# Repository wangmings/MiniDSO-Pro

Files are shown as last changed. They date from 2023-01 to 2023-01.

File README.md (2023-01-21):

# MiniDSO-Pro

#### 介绍
B站老刘示波器Pro版本，在原版的基础上，扩展了测量负电压的功能，更新了UI设计，屏幕升级为1.3寸OLED屏。你可以在doc文件夹，获取设计报告和相关的芯片数据手册。

请大家务必给我个Star！！！这真的很重要！

B站视频演示：[点击我观看](https://www.bilibili.com/video/BV1M5411u7B6)

3D仿真效果图:
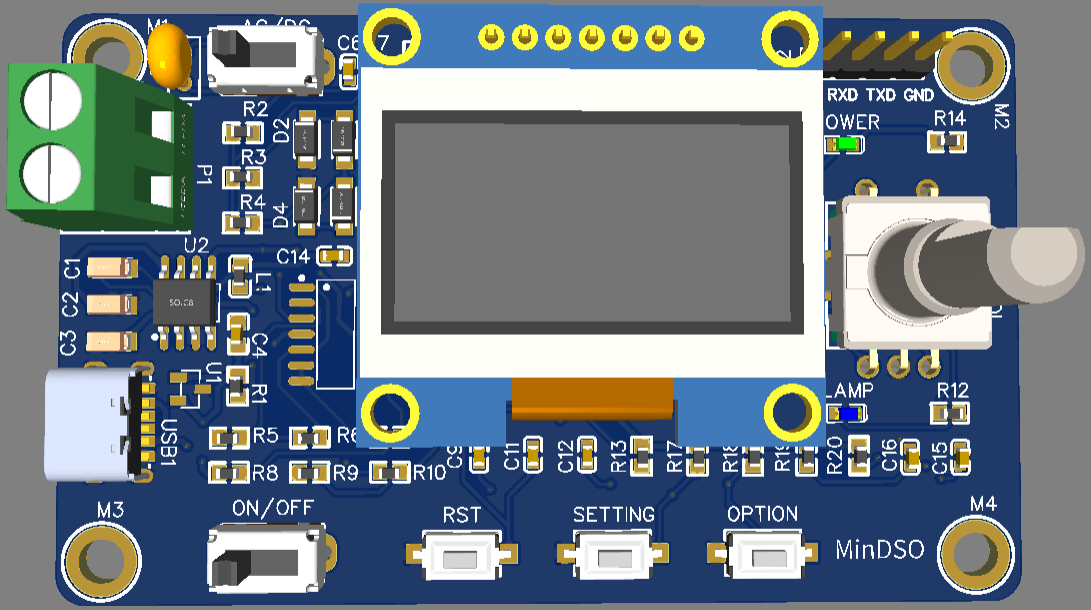
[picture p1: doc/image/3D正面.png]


2D仿真效果图:
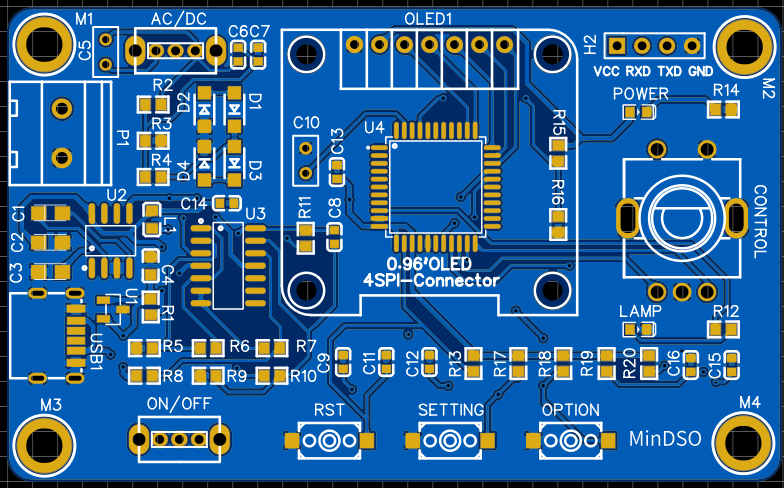
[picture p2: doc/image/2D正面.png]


实物效果图:
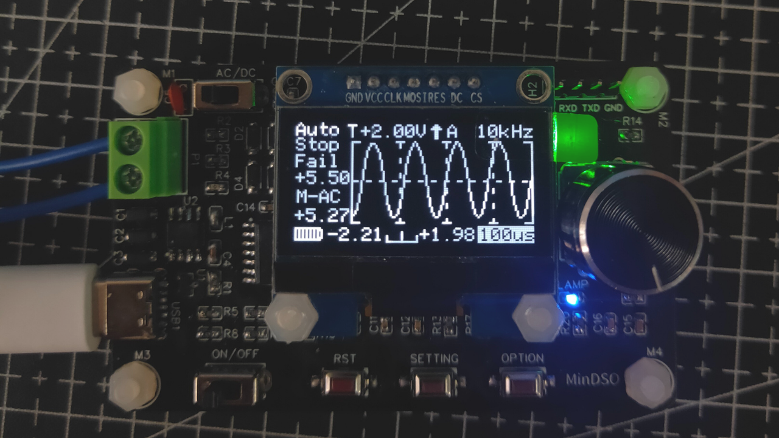
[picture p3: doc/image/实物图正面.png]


#### 系统架构

Mini示波器采用了一套成本低廉但高效的硬件，配合层次化的软件框架，实现对常规低频信号波形的采集、分析、显示。

硬件部分的主要工作有：电源管理（5V、2.5V、-5V）；对信号的衰减、限幅、偏置。最后将处理好的电压信号送入MCU的ADC外设，进行数据采集。由于ADC外设只能采集正电压，因此我们通过增加偏置电压的方式，将负电压抬高来采集。

软件部分的主要工作有：底层驱动SDK框架、ADC滤波算法、波形数据处理、人机交互界面。SDK提供基本的模块和外设驱动支持，滤波算法去除噪声和毛刺，波形处理计算电压值和频率，并为波形显示做准备；人机交互界面提供屏幕显示（OLED屏）和操作方式（旋钮和按键）。

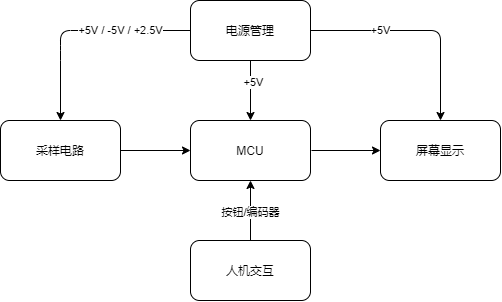
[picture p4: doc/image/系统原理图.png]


#### 与原版对比

这一版本的Mini示波器-Pro，相比于原版对硬件部分做了很大扩展，使其可以测到负电压。软件部分修改了有30%，主要是在数据处理和UI显示部分。

#### 调参教程

示波器采样的原理与原版一致，但是由于硬件上加了许多电路，导致信号呈非线性变化，因此需要对系统计算的结果进行处理。

这里提供两种办法：

##### 1. 对原采样方法进行改进
原版的采样模式，是利用了芯片自带的12位ADC进行采样，所以可以对ADC的采样函数进行优化。原版使用了查询法，通过循环等待采样完成标志位，获取采样结果。

频率的计算，是根据不同的采样时间（delay延时等待法），来分段计算频率值。这里可以通过定时器来控制采样时间，提高精确度。

##### 2. 对原采样结果上进行拟合

直接在原版的采样结果上进行数据拟合，这样做比较快捷，也是我用的方法（主要是赶时间）。但是误差较大，且需要测算的数据量有一点多。

具体的方法是，首先记录原采样的结果，电压幅度的刻度为0.5V，范围是从0V到20V。 频率的刻度为1KHz，范围是从0KHZ到20KHz。将测算的结果与输入的信号，一一对应拟合出计算公式，我采用的Excel来操作，选择的是对数函数来拟合，数据有误差。

具体需要拟合的函数在chart.c文件中，函数名称如下：

```C
/* 需要拟合数据的函数如下：*/
void getWaveFreq(void);
void AnalyseData(void);

/* 拟合数据的结果存放在如下变量：*/
VMax_m  /* 存放电压最大值 */
VMin_m  /* 存放电压最小值 */
Mvoltage  /* 存放电压平均值 */

WaveFreq   /* 存放频率值 */

```
开发者在调参的时候，可以屏蔽我的拟合代码，进行原方法采样结果的记录，然后进行数据拟合。我会在代码中进行标注，方便开发者查找和修改。

#### 需要改进的地方

1.硬件的性能还没有全部发挥出来，测量幅度还可以更高。
2.MCU的性能还没有榨干，比如没有用上硬件SPI，提高屏幕刷新率。

#### 开发后记

1.最一开始设想的方案，我是想用上我写的AntOS操作系统的，但是初版操作系统，为合作式调度，实际使用的过程中，并没有达到我的预期效果，所以选择在老刘示波器的基础工程上修改和优化。

2.硬件设计主要参考了B站`唐老师讲电赛`大佬提供的方案，实际使用的过程中，我又微调了一部分，建议大家可以去阅读一下硬件电路中使用的几种芯片数据手册，这样心里更有底，不然遇到问题不好排查。

3.大多数元器件，我用的都是0603的封装，这样可以让PCB板设计的更小巧更紧凑，但是不好焊接。

4.下一版本，我将使用STC8AxD4作为主控（因为有DMA）,软件上使用我现在编写AntOS（已支持抢占式调度），进一步提高示波器的性能。

####原版示波器Github仓库连接

[点击我跳转]( https://github.com/CreativeLau/Mini-DSO)

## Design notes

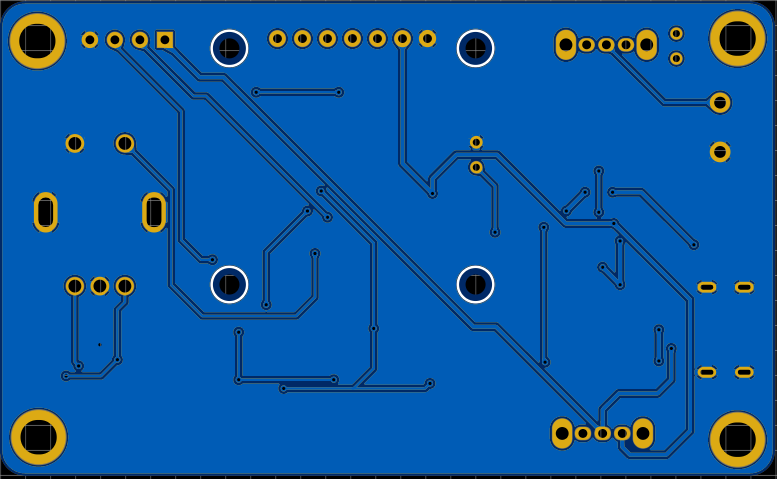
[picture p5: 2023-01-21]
doc/image/2D反面.png

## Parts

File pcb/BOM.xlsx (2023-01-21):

ID | Name | Designator | Footprint | Quantity | Manufacturer Part | Manufacturer | Supplier | Supplier Part | Price | JLCPCB Part Class
1 | SS-12D02-VG4 | AC/DC,ON/OFF | SW-TH_SS-12D02-VG4 | 2 | SS-12D02-VG4 | Rectangular Connectors - Contacts | LCSC | C136719 | 0.4547
2 | 10uF | C1,C2,C3 | CASE-A_3216 | 3
3 | 4.7uf | C4 | C0603 | 1 |  |  | LCSC
4 | 100nF(104) | C5 | 插件陶瓷电容 | 1 | CY1331KE1IEB45G0A2 | Dersonic | LCSC | C263248 | 0.1958 | Extended Part
5 | 30pF | C6,C7 | C0603 | 2
6 | 1uF | C8,C9,C11,C12 | C0603 | 4
7 | 1000pF | C10 | 插件陶瓷电容 | 1 | 102M 400V Y5V | ReliaPro | LCSC | C3704 | 0.1942
8 | 0.1uF | C13,C14,C15,C16 | C0603 | 4
9 | EC11E152U402 | CONTROL | SW-TH_EC11XXXXXXXX | 1 | EC11E152U402 | ALPS Electric | LCSC | C110313 | 32.76
10 | 1N4148W | D1,D2,D3,D4 | SOD-123FL_L2.6-W1.6-LS3.4-RD | 4 | 1N4148W | Tak Cheong | LCSC | C129216 | 0.0901
11 | HDR-F-2.54_1x4 | H2 | HDR-M-2.54_1X4 | 1 |  |  | LCSC | C225501 | 0.4719
12 | 0.1uH | L1 | L0603 | 1
13 | LED-0603_B | LAMP | LED0603_BLUE | 1 | 19-217/BHC-ZL1M2RY/3T | EVERLIGHT(台湾亿光) | LCSC | C72041 | 0.1007
14 | M3螺丝孔 COPY | M1,M2,M3,M4 | M3螺丝孔 | 4
15 | 0.96OLED_7P | OLED1 | 0.96OLED_7P | 1 |  |  | LCSC
16 | K2-3.6×6.1_SMD | OPTION,RST,SETTING | KEY-SMD_2P-L6.2-W3.6-LS8.0 | 3 | K2-1107ST-A4SW-06 |  | LCSC | C118141 | 0.341
17 | WJ128V-5.0-2P | P1 | CONN-TH_2P-P5.00_WJ128V-5.0-2P | 1 | WJ128V-5.0-2P | ReliaPro | LCSC | C8269 | 0.7299 | Extended Part
18 | LED-0603_G | POWER | LED0603_GREEN | 1 | 19-217/GHC-YR1S2/3T | EVERLIGHT(台湾亿光) | LCSC | C72043 | 0.1549
19 | 649Ω | R1 | R0603 | 1
20 | 2k | R3 | R0603 | 1
21 | 0Ω | R4 | R0603 | 1
22 | 1.8k | R5 | R0603 | 1
23 | 3.2k | R6 | R0603 | 1
24 | 4.7k | R7,R8,R9,R10 | R0603 | 4
25 | 10Ω | R11 | R0603 | 1
26 | 10K | R2,R15 | R0603 | 2
27 | 2K | R16 | R0603 | 1
28 | 3.3k | R12,R13,R14,R17,R18 | R0603 | 5
29 | 10k | R19,R20 | R0603 | 2
30 | TL431 | U1 | SOT-23-3_L2.9-W1.3-P1.90-LS2.4-BR | 1 | TL431 | ZRE(治润) | LCSC | C779770 | 0.1699
31 | ICL7660SCBAZ-T | U2 | SOIC-8_L4.9-W3.9-P1.27-LS6.0-BL | 1 | ICL7660SCBAZ-T | Renesas Electronics | LCSC | C357815 | 6.3 | Extended Part
32 | TL074CDT | U3 | SOIC-14_L8.7-W3.9-P1.27-LS6.0-BL | 1 | TL074CDT | STMicroelectronics | LCSC | C6963 | 1.5521 | Extended Part
33 | STC8A8K64S4A12-C83896 | U4 | LQFP-44_L10.0-W10.0-P0.80-LS12.0-BL | 1 | STC8A8K64S4A12 | STC Micro | LCSC | C83896 | 24.75 | Extended Part
34 | TYPEC-250D-BCP6 | USB1 | USB-C-SMD_TYPEC-250D-BCP6 | 1 | TYPEC-250D-BCP6 | XUNPU | LCSC | C720626 | 0.4803

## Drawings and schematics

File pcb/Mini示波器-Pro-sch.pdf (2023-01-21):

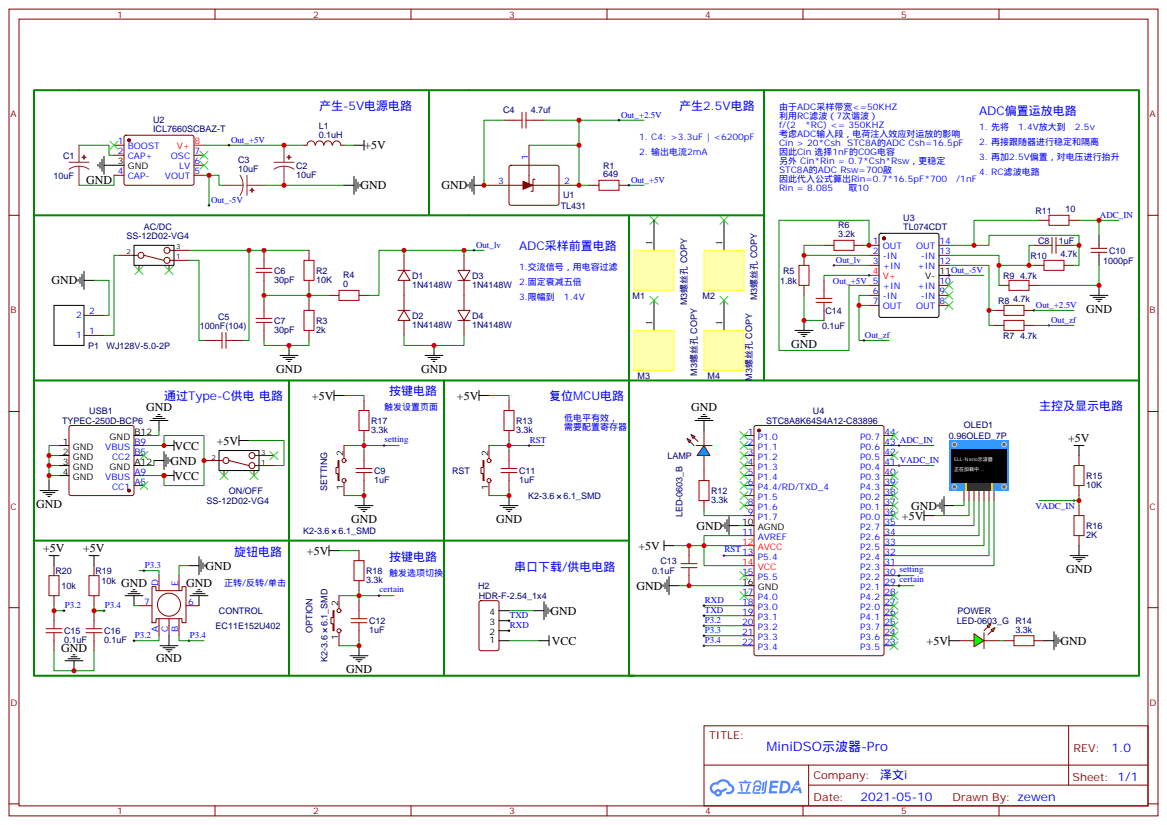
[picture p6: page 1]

+IN 10 V- 11 +IN 12 -IN 13 OUT 14

CC1 A5 VBUS A9 GND A12 CC2 B5 VBUS B9 GND B12

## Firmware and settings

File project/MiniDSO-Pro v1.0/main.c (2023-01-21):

/*

    简易示波器

    操作说明：
        主界面-选项设置模式（按Option按键）：
            单击编码器：切换开始/暂停采样
            按下同时旋转编码器：在参数间切换

        主界面-波形水平滚动模式：
            单击编码器：切换开始/暂停采样
            旋转编码器：水平滚动波形（在暂停采样状态下有效）
            按下同时旋转编码器：垂直滚动波形（仅在暂停采样状态下有效）
            
        设置界面（按Setting按键）：

            长按编码器：返回主界面
            旋转编码器：修改当前选项
            按下同时旋转编码器：切换选项

    主界面参数：
        横轴时间区间："500ms", "200ms", "100ms", "50ms", "20ms", "10ms","5ms", "2ms", "1ms", "500us", "200us", "100us"(100us仅在自动触发模式下可用)
        纵轴电压区间：设定电压量程上限，最大30V，顺时针旋转编码器将电压上限设置为0则进入自动量程，逆时针旋转进入手动量程
        触发值：设定触发电压值，触发位置被放在屏幕中心
        触发方向：上下箭头，分别代表上升沿触发和下降沿触发
        触发方式：
            Auto(自动触发)  ：连续采样，指示灯始终点亮，通过单击编码器控制启停；触发成功时，触发点位于屏幕中心，触发失败则波形无规律滚动，屏幕左侧显示Fail标志
            Normal(普通触发)：等待预采样，待指示灯亮起表示预采样结束，这时可以输入信号；
                              触发成功后，显示波形，并继续等待下次触发；
                              如果有新的触发成功，则自动显示新的波形，如没有新的触发成功则屏幕波形保持并一直等待下次触发；
                              需注意设置正确的触发值，否则一直处于等待触发状态，屏幕不会显示波形
            Single(单次触发)：等待预采样，待指示灯亮起表示预采样结束，这时可以输入信号；
                              触发成功后，显示波形，并停止采样，需用户单击编码器开始下次采样	
                              需注意设置正确的触发值，否则一直处于等待触发状态，屏幕不会显示波形
            
    主界面状态显示：	
        Run：正在采样
        Stop：停止采样
        Fail：自动模式下，触发值超出波形范围引起触发失败
		Succe：自动模式下，触发值在波形范围显示触发成功
        Auto：自动量程
            
    设置界面选项：
        PMode(绘图模式)：
            Vector：波形以矢量显示
            Dots  ：波形以点阵显示
        LSB(采样系数)：分压系数的100倍，比如用10k加2k的电阻进行分压，分压系数为(10+2/2)=6，LSB理论取值为6x100=600，根据实际电阻精度进行微调	
        BRT：OLED亮度

    保存设置：长按编码器退出设置界面时，设置界面和主界面的所有参数被保存到EEPROM


	
	
*/

#include <reg51.h>
#include "global.h"
#include "delay.h"
#include "adc_stc8.h"
#include "config_stc.h"
#include "settings.h"
#include "chart.h"
#include "ssd1306.h"
#include "stdio.h"

sfr P5 = 0xC8;

char putchar (char c)
{
    if (c == '\n')
    {
        SBUF = 0x0d;
		while (!TI);	//等待发送成功
		TI = 0;	  //清除发送中断标志
        /* output CR  */
    }
    SBUF = c;
    while (!TI);	//等待发送成功
    TI = 0;	  //清除发送中断标志
    return c;
}

void Timer1Init(void)		//20毫秒@27.000MHz
{
	AUXR &= 0xBF;		//定时器时钟12T模式
	TMOD &= 0x0F;		//设置定时器模式
	TL1 = 0x38;		//设置定时初始值
	TH1 = 0x50;		//设置定时初始值
	TF1 = 0;		//清除TF1标志
	TR1 = 1;		//定时器1开始计时
}

sfr T2H = 0xD6;
sfr T2L = 0xD7;

void UartInit(void)		//9600bps@24.000MHz
{
	SCON = 0x50;		//8位数据,可变波特率
	AUXR |= 0x01;		//串口1选择定时器2为波特率发生器
	AUXR |= 0x04;		//定时器时钟1T模式
	T2L = 0x8F;		//设置定时初始值
	T2H = 0xFD;		//设置定时初始值
	AUXR |= 0x10;		//定时器2开始计时
	
}


void init()
{
	
    InSettings = 0;         //初始化开机界面
    OptionInSettings = 0;   //初始化设置界面的选项编号
    OptionInChart = 0;      //初始化主界面的选项标号
    WaveScroll = 0;         //清零波形滚动标志
    OptionChanged = 0;      //清零设置修改标志
    ADCRunning = 1;         //置位采样标志
    ADCInterrupt = 0;       //清零ADC中断标志
    ADCComplete = 0;        //清零ADC完成标志
    WaveUpdate = 0;         //清零波形更新标志
    ClearWave = 0;          //清零清除波形标志
    ClearDisplay = 1;       //置位清空屏幕标志
    EC11PressAndRotate = 0; //清零编码器旋转标志
    UpdateVbat = 0;         //清零采样电池电压标志
    ADCComplete = 0;        //清零ADC完成采样标志
    WaveFreq = 0;           //清零波形频率
    TriPos = 50;            //初始化触发点位置
    TriPosOffset = 0;       //初始化触发点偏移量
    TriFail = 0;            //清零触发失败标志
    VMax = 0;               //清零波形电压最大值
    VMin = 0;               //清零波形电压最小值
    WaveLengthSumNum = 0;   //清零波形长度求和次数
    WaveLengthSum = 0;      //清零波形长度求和
	
	PlotMode = 0;
	
	Bias_Voltage = 8900; //偏置电压权重
	
	TriLevel_m = 2000;
	
	VMax_m = 0;
	VMin_m = 0;
	Mvoltage = 0;
	RulerVMax_m = 0;
	
	MeaWay = Option_MeaWay_AC;
	
    /* 波形滚动模式下正在采样则禁用外部中断0（编码器旋转）
       Disable external interrupt 0(Encoder rotation) in waveform scroll mode when sampling*/
    if (ADCRunning && WaveScroll)
        EX0 = 0;

    /* 获取内部参考电压值
       Get internal reference voltage */
    BGV = GetBGV();
}

void runWhenInSettrings()
{
    P_Ready = 0;
    ClearDisplay = 1;
    while (InSettings)
    {
        /* 更新电池电压信息
           Update voltage infor of battery */
        if (UpdateVbat)
        {
            UpdateVbat = 0;
            VBat = GetVoltage(ADC_BAT, VBAT_LSB);
        }
		
        /* 更新屏幕亮度
           Update OLED Brightness */
        if (OLED_BrightnessChanged)
        {
            OLED_BrightnessChanged = 0;
            OLED_Write_Command(0x81);
            OLED_Write_Command(OLED_Brightness * 10);
        }

        /* 更新参数
           Update parameters */
        if (DisplayUpdate)
        {
            DisplayUpdate = 0;
            PlotSettings();
            OLED_Display();
        }
    }

    /* 保存设置
       Save Settings */
    EA = 0;
    if (OptionChanged)
    {
        OptionChanged = 0;
        ClearDisplay = 0;
        /* 保存设置并显示保存状态
           Save settings and display saving status*/
        PlotSaveStatus(Save_Options());
        OLED_Display();
        Delay1000ms();
    }

    /* 退出settings后刷新屏幕
       Redraw display after exit settings */
    ClearDisplay = 1;
    PlotChart();
    OLED_Display();
    IE0 = 0;
    IE1 = 0;
    EA = 1;
}

/*
    ADCRuning=1
    |	WaveUpdate=1
    |	|	ClearWave=1
    |	|	ClearWave=0
    |	WaveUpdate=0
    ADCRuning=0
        DisplayUpdate=1
            WaveUpdate=1
            |	ClearWave=1
            |	ClearWave=0
            WaveUpdate=0
*/
void runWhenADCInterrupt()
{
    ADCInterrupt = 0;
    P_Ready = 0;

    /* ADC采样运行
       ADC Sampling Running */
    if (ADCRunning)
    {
        EX0 = 0;

        if (WaveUpdate)
        {
            WaveUpdate = 0;
            ClearDisplay = 1;

            /* 清空波形缓存
               Clear waveform in buffer*/
            if (ClearWave)
            {
                ClearWave = 0;
                memset(ADCbuf, 0x00, SAMPLE_NUM * 2);
                WaveFreq = 0;
                TriFail = 0;
                VMax = 0;
                VMin = 0;
                PlotChart();
            }
            /* 显示缓存中的波形
               Display waveform in buffer*/
            else
            {
                AnalyseData();
                PlotChart();
                PlotWave();
            }
        }
        else
        {
            ClearDisplay = 0;
            PlotChart();
        }
        OLED_Display();

        /* ADCRuning和WaveScroll同时置位时，不开启外部中断0（编码器旋转）
           Not to enable external interrupt 0(Encoder Rotation) when both of ADCRunning and WaveScroll set. */
        if (!WaveScroll)
        {
            IE0 = 0;
            EX0 = 1;
        }
    }

    /* ADC采样停止
       ADC Sampling Stopped */
    else
    {
        while (!ADCRunning && !InSettings)
        {
            if (DisplayUpdate)
            {
                EX0 = 0;
                DisplayUpdate = 0;
                if (WaveUpdate)
                {
                    WaveUpdate = 0;
                    /* 分析缓存中完成采样的采样数据
                       Analyse completed sampling data in buffer */
                    AnalyseData();
                    ClearDisplay = 1;

                    /* 清空屏幕，绘制波形
                       Clear display and draw waveform */
                    if (ScaleH == ScaleH_tmp)
                    {
                        /* 采样点数有限，不支持横向缩放波形，只有时间区间与完成采样的时间区间相同才绘制波形
                           Since the sampling points limitation, scaling waveform along horizontal is not support.
                           Show waveform only when time scale is same as that when sampling completed */
                        PlotChart();
                        PlotWave();
                    }

                    /* 清空屏幕，不绘制波形
                       Clear display and no waveform */
                    else
                    {
                        WaveFreq = 0; //清零WaveFreq，绘制界面时，频率位置会显示****Hz
                        PlotChart();
                    }
                }
                /* 只更新屏幕上的参数，波形不变
                   Update parameters on display only, keep waveform */
                else
                {
                    ClearDisplay = 0;
                    PlotChart();
                }

                OLED_Display();
                IE0 = 0;
                EX0 = 1;
            }
        }
    }
}

void runWhenADCComplete()
{
    /*  ADC采样完成 - 单次触发
        ADC Sampling Complete - Single Trigger Mode */
    if (TriMode == 2)
    {
        EX0 = 0;
        ADCInterrupt = 1;
        DisplayUpdate = 0;
        WaveUpdate = 0;
        ADCRunning = 0; //清零ADC运行标志，停止采样
        AnalyseData();
        ClearDisplay = 1;
        PlotChart();
        PlotWave();
        OLED_Display();
        IE0 = 0;
        EX0 = 1;
    }

    /*  ADC采样完成 - 自动触发或普通触发
        ADC Sampling Complete - Auto or Normal Trigger Mode */
    else
    {
        //EX0 = 0;
        ClearDisplay = 1; //置位清空屏幕标志
        AnalyseData();    //分析采样数据
        PlotChart();      //绘制主界面
        PlotWave();       //绘制波形
        OLED_Display();
        //IE0 = 0;
        //EX0 = 1;
    }
}

/* 程序入口
   Program Entry */
void main()
{
    /* 将ADC端口P0.4，P0.6设置为高阻
       Set ADC port P0.4, P0.6 as high-impedance */
    P0M1 |= 0x50;
    P0M0 &= ~0x50;

    /* 设置指示灯端口P1.1为推挽输出
       Set indicator port P1.1 as push-pull output */
    P0M1 &= ~0x02;
    P0M0 |= 0x02;

    /* 设置编码器端口P3.2，P3.3，P3.4为准双向
       Set Encoder port P3.2, P3.3, P3.4 as quasi bidirectional */
    P3M1 &= ~0x1C;
    P3M0 &= ~0x1C;

    /* 设置OLED端口P2.3，P2.4，P2.5，P2.6，P2.7为准双向
       Set OLED port P2.3, P2.4, P2.5, P2.6 as quasi bidirectional */
    P2M1 &= ~0xF8;
    P2M0 &= ~0xF8;
	
    P0M1 |= 0x03;
    P0M0 &= ~0x03;
	
    /* 编码器旋转外部中断 
       Interrupt for rotating of Encoder */
    IT0 = 0; //外部中断0触发方式，上升沿和下降沿
    PX0 = 1; //外部中断0高优先级，可打断按键中断，用于判断按下同时旋转
    EX0 = 1; //开启外部中断0

    /* 编码器按键外部中断 
       Interrupt for clicking of Encoder */
    IT1 = 1; //外部中断1触发方式，下降沿
    PX1 = 0; //外部中断1低优先级
    EX1 = 1; //开启外部中断1

    /* 定时器0，为更新电池电压信息计时
       Timer 0, for updating voltage of battery */
    AUXR &= 0x7F; //定时器时钟12T模式
    TMOD &= 0xF0; //设置定时器模式
    TL0 = 0x46;   //设置定时初值 //27MHz，25ms
    TH0 = 0x24;   //设置定时初值
    TF0 = 0;      //清除TF0标志

    ET0 = 1;      //允许定时器0中断
	
	UartInit();
	Timer1Init();
	
    ET1 = 1;      //允许定时器1中断	
	
	
    Read_Options();
    init();
	Delay18us();
    OLED_Init();
    OLED_SetFontWidth(6);
    PlotChart();
    OLED_Display();
	
	/* 开总中断
   Enable global interrupt */
	EA = 1;
	
	
    while (1)
    {
        P_Ready = 0;
		
        /* 更新电池电压信息
           Update voltage infor of battery */
        if (UpdateVbat)
        {
            UpdateVbat = 0;
            VBat = GetVoltage(ADC_BAT, VBAT_LSB);
        }
		
        /* 采样波形
           Sampling*/
        GetWaveData();

        /* 进入设置界面
           Enter Settings Interface */
        if (InSettings)
        {
            runWhenInSettrings();
        }

        /* ADC采样中断
           ADC Sampling Interrupt */
        else if (ADCInterrupt)
        {
            runWhenADCInterrupt();
        }

        /* ADC采样完成
           ADC Sampling Complete */
        else
        {
            runWhenADCComplete();
        }
    }
}

/* 分析编码器旋转
   Analyse Rotation of Encoder */
void Scan_EC11(void)
{
    /* 延时去抖动
       Delay to remove jitter */
    Delay500us();

    /* 正转
       Clockwise */
    if (EC11_A != EC11_B)
    {
        Change_Val(1);
    }

    /* 反转
       Anticlockwise */
    else if (EC11_A == EC11_B)
    {
        Change_Val(0);
    }
}

/* 编码器旋转中断
   Interrput for Encoder Rotated */
void INT0_interrupt(void) interrupt INT_0
{
    Delay500us();

    /* 编码器是否被按下
       Whether the Encoder is pressed */
    if (!EC11_KEY)
        EC11PressAndRotate = 1;
    else
        EC11PressAndRotate = 0;

    Scan_EC11();
    ADCInterrupt = 1;
    DisplayUpdate = 1;
	
    IE1 = 0; //清零外部中断1标志位
    IE0 = 0; //清零外部中断0标志位
}

/* 编码器点击中断
   Interrput for Encoder Pressed */
void INT1_interrupt(void) interrupt INT_1
{
    Delay50ms();
    if (!EC11_KEY)
    {
        EC11PressAndRotate = 0;
		
        /*  按住编码器同时旋转
            Rotate Encoder while pressing  */
        if (EC11PressAndRotate)
        {
            /* 由编码器旋转中断执行操作
               Operations Performed by Interrupt of Encoder Rotation */
        }
		
        /*  单击编码器按键 - 在主界面，切换Stop/Run状态
            Single click Encoder - Switch Run/Stop in main interface    */
			
        else if (!InSettings)
        {
            EX0 = 0;
            ADCRunning = ~ADCRunning;
            if (ADCRunning)
            {
                WaveUpdate = 1;
                ClearWave = 1;
            }
            else
            {
                DisplayUpdate = 1;
                WaveUpdate = 1;
            }
            ADCInterrupt = 1;
            IE0 = 0;
            IE1 = 0;
        }
    }
    IE1 = 0;
}

/* 为更新Vbat计时
   Timer for updating Vbat */
void TIMER0_interrupt(void) interrupt TIMER_0
{
    static uint8 n;

    if (++n >= VBAT_UPDATE_FREQ)
    {
        n = 0;
        UpdateVbat = 1;
        DisplayUpdate = 1;
    }
}


TIMER1_ISR(void) interrupt  3
{
	static uint8 Trg1,read1,cont1;
	static uint8 Trg2,read2,cont2;
	static uint8 Trg3,read3,cont3;
	
	read1 = (P2 & 0x02) ^ 0x02;
	Trg1  = (read1 ^ cont1)  &	read1; 
	cont1 = read1;
	 
	read2 = (P2 & 0x04) ^ 0x04;
	Trg2  = (read2 ^ cont2) & read2; 
	cont2 = read2;
	
	read3 = P5 ^ 0xff;
	Trg3  = (read3 ^ cont3) & read3; 
	cont3 = read3;
	
	if(Trg1)
	{
		/* 主界面
		   Main Interface */
		if (!InSettings)
		{
			WaveScroll = ~WaveScroll;
			OptionChanged = 1;
			ADCInterrupt = 1;
			DisplayUpdate = 1;
			ClearWave = 0;
		}

		Trg1 = 0;
	}
	
	if(Trg2)
	{
			
			InSettings = ~InSettings;

			/*  进入设置界面
				Enter Settings  */
			if (InSettings)
			{
				DisplayUpdate = 1;
				UpdateVbat = 1;
				TF0 = 0; //清零定时器0溢出标志
				TR0 = 1; //定时器0开始计时，开始电池电压信息更新计时
				IE0 = 0; //清零外部中断0中断标志
				EX0 = 1; //开启外部中断0（编码器旋转）
			}
			/*  回到主界面
				Retrurn to main interface   */
			else
			{
				TR0 = 0; //清零定时器0溢出标志
				TF0 = 0; //定时器0停止计时，停止电池电压信息更新计时
				WaveFreq = 0;
				TriFail = 0;
				VMax = 0;
				VMin = 0;
				DisplayUpdate = 1;
				WaveUpdate = 1;
				ClearWave = 0;
			}
			
			ADCInterrupt = 1;	

		Trg2 = 0;
	}

    if(Trg3)
    {

        SP = 0;
        Trg3 = 0;
    }
}

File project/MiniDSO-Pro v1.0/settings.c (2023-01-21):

/*
    settings.c

    Settings Control and Parameter Adjusting

    Copyright (c) 2020 Creative Lau (creativelaulab@gmail.com)

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
*/

#include "settings.h"

    //单片机速度限制，单次和普通触发的中间计算造成单片机无法完成100us区间计算
    //MCU speed limitation result in the Single Sweep and Normal Sweep calculations could not complete in 100us time interval.
void Check_MinTimeInterval()
{
    if (TriMode)
    {
        if (ScaleH > SCALE_H_MAX - 1)
            ScaleH = SCALE_H_MAX - 1;
    }
    else
    {
        if (ScaleH > SCALE_H_MAX)
            ScaleH = SCALE_H_MAX;
    }
}

void change_ScaleH(bit i)
{
    if (i)
    {
        ScaleH++;
        Check_MinTimeInterval();
    }
    else
    {
        ScaleH--;

        if (ScaleH < SCALE_H_MIN)
            ScaleH = SCALE_H_MIN;
    }
}

void change_TriggerValue(bit i)
{
    if (i)
    {
        if (TriLevel_m >= 5000)
            TriLevel_m += 500;
        else
            TriLevel_m += 100;

        if (TriLevel_m > MAX_V)
            TriLevel_m = MAX_V;
    }
    else
    {
        if (TriLevel_m <= 5000)
            TriLevel_m -= 100;
        else
            TriLevel_m -= 500;

        if (TriLevel_m < MIN_V)
            TriLevel_m = MIN_V;
    }
	
	 TriLevel = TriLevel_m + 11100;
}

void change_LSB(bit i)
{
    if (i)
    {
        Lsb++;

        if (Lsb > LSB_MAX)
            Lsb = LSB_MAX;
    }
    else
    {
        Lsb--;

        if (Lsb < LSB_MIN)
            Lsb = LSB_MIN;
    }
}

void change_PlotMode()
{
    PlotMode = ~PlotMode;
}

void change_TriMode(bit i)
{
    if (i)
    {
        TriMode++;

        if (TriMode > 2)
            TriMode = 0;
    }
    else
    {
        TriMode--;

        if (TriMode < 0)
            TriMode = 2;
    }
}

void change_TriPosOffset(bit i)
{
    if (i)
    {
        TriPosOffset--;
        if (TriPosOffset + TriPos < ((CHART_H_MAX - CHART_H_MIN) >> 1))
            TriPosOffset = ((CHART_H_MAX - CHART_H_MIN) >> 1) - TriPos;
    }
    else
    {
        TriPosOffset++;
        if (TriPosOffset + TriPos > SAMPLE_NUM - ((CHART_H_MAX - CHART_H_MIN) >> 1) - 1)
            TriPosOffset = SAMPLE_NUM - ((CHART_H_MAX - CHART_H_MIN) >> 1) - 1 - TriPos;
    }
}

void change_OptionInChart(bit i)
{
    if (i)
    {
        OptionInChart++;

        if (OptionInChart > 5)
            OptionInChart = 0;
    }
    else
    {
        OptionInChart--;

        if (OptionInChart < 0)
            OptionInChart = 5;
    }
}

void change_OptionInSettings(bit i)
{
    if (i)
    {
        OptionInSettings++;
        if (OptionInSettings > 2)
            OptionInSettings = 0;
    }
    else
    {
        OptionInSettings--;
        if (OptionInSettings < 0)
            OptionInSettings = 2;
    }
}

void change_RulerVMax(bit i)
{
    if (i)
    {
        if (RulerVMax <= 1000)
        {
            RulerVMax -= 100;
            RulerVMax_m -= 100;
        }
        else
        {
            RulerVMax -= 500;
            RulerVMax_m -= 500;
        }

        if (RulerVMax <= RulerVMin)
            ScaleV_Auto = 1;
    }
    else
    {
        ScaleV_Auto = 0;
        if (RulerVMax >= 1000)
        {
            RulerVMax += 500;
           RulerVMax_m += 500;
        }
        else
        {
            RulerVMax += 100;
            RulerVMax_m += 100;
        }

        if (RulerVMax > MAX_V)
		{
            RulerVMax = MAX_V;
			RulerVMax_m = MAX_V;
		}
    }
}

void change_RulerV(bit i)
{
    ScaleV_Auto = 0;
    if (i)
    {
        RulerVMax -= 100;
        RulerVMin -= 100;
		RulerVMax_m -= 100;
        if (RulerVMin < MIN_V + 100)
        {
            RulerVMax += 100;
            RulerVMin = MIN_V;
        }
    }
    else
    {
		RulerVMax_m += 100;
        RulerVMax += 100;
        RulerVMin += 100;
        if (RulerVMax > MAX_V)
        {
            RulerVMax = MAX_V;
			RulerVMax_m = MAX_V;
            RulerVMin -= 100;
        }
    }
}

void change_OLED_Brightness(bit i)
{
    if (i)
    {
        OLED_Brightness++;
        if (OLED_Brightness > BRIGHTNESS_MAX)
            OLED_Brightness = BRIGHTNESS_MAX;
    }
    else
    {
        OLED_Brightness--;
        if (OLED_Brightness < BRIGHTNESS_MIN)
            OLED_Brightness = BRIGHTNESS_MIN;
    }
    OLED_BrightnessChanged = 1;
}
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
